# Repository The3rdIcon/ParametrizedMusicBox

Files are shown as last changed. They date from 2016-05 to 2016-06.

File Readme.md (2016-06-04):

# Program to generate a customizable music box
The midiToNote python file can be run as follows
```
python midiToNote.py <midi file name> <track in midi to encode>
```
```
python midiToNote.py hot_cross_buns.mid 1

Could not find name of track
***********_******
***********_******
*********_********
*********_********
*******_**********
*******_**********
***********_******
***********_******
*********_********
*********_********
*******_**********
*******_**********
*******_**********
*******_**********
*******_**********
*******_**********
*******_**********
*******_**********
*******_**********
*******_**********
*********_********
*********_********
*********_********
*********_********
*********_********
*********_********
*********_********
*********_********
***********_******
***********_******
*********_********
*********_********
*******_**********
*******_**********

oooooooooooXoooooooooooooooooXoooooooooooooooXoooooooooooooooooXoooooooooooooooXoooooooooooooooooXoooooooooooooooooooooXoooooooooooooooooXoooooooooooooooXoooooooooooooooooXoooooooooooooooXoooooooooooooooooXoooooooooooooooooXoooooooooooooooooXoooooooooooooooooXoooooooooooooooooXoooooooooooooooooXoooooooooooooooooXoooooooooooooooooXoooooooooooooooooXoooooooooooooooooooXoooooooooooooooooXoooooooooooooooooXoooooooooooooooooXoooooooooooooooooXoooooooooooooooooXoooooooooooooooooXoooooooooooooooooXoooooooooooooooooooXoooooooooooooooooXoooooooooooooooXoooooooooooooooooXoooooooooooooooXoooooooooooooooooXoooooooooo

C 4C#4D 4D#4E 4F 4F#4G 4G#4A 4A#4B 4C 5C#5D 5D#5E 5F 5

Timeslots: 34

```

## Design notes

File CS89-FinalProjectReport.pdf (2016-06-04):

# The Music Box Project

## Lau, Moreno, Solanky

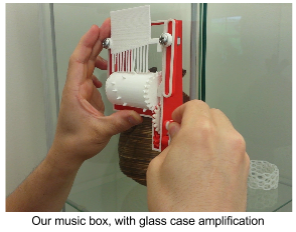
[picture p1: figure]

## 1. Motivation

Historically, humans have produced musical instruments from as wide a variety of materials and technologies as they have had access to. The profound power of computational fabrication lies in a greater facility for reproducing a work of imagination precisely in physical form. The ideal version of our project would enable a user to simply hum or whistle a tune into their microphone or take a picture of some sheet music, and automatically produce the design for a music box that would faithfully reproduce the user’s input.

## 2. Related Work

The resonant qualities of plastic are generally not suitable for musical instruments, which is why they are commonly made from metal or wood. However, working musical instruments have been made with 3D printers. Engineer Hans Fouche⁴ and industrial designer Scott Summit

6 have both
independently printed working guitars. The sound of string instruments and music boxes both work via the principle of forced vibration, indicating that the acoustics of 3D printed music boxes can sound good, even in plastic.

Very little work has been done in the specific area of 3D printable music boxes. Philipp Tiefenbacher, aka wizard23, published a scad file for a working music box on Thingiverse⁷
, a website for users to share open source design files. Tiefenbacher’s music box has several drawbacks. The comb and the case are produced as a single piece, which is inefficient for iteration and customization and damps the vibration of the comb unnecessarily. The herringbone gears have small crevices in which stuck support material and small errors in fabrication can produce noise and cause the gears to come out of alignment.

MIT students Tiffany Lu and Trevor Walker have also published code on GitHub
for producing an entirely 3D printed music box.

3 Their design initially called for a

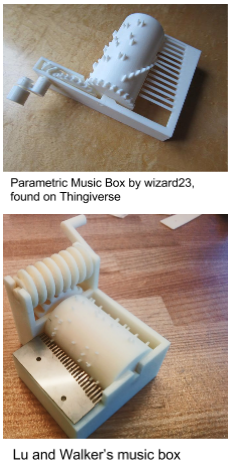
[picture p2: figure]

laser cut steel comb, however the steel was not flexible enough and broke the plastic pins off the cylinder.

The plastic comb they used instead did not have good acoustic qualities. For the playing mechanism, they used a large worm gear that was both materially inefficient and difficult to use.

We decided to use Tiefenbacher’s design as a starting point for several reasons. The design is compact, the code is relatively well structured for augmentation, and most importantly the comb produces a workable sound.

## 3. Technical Approach

## A. Modularity

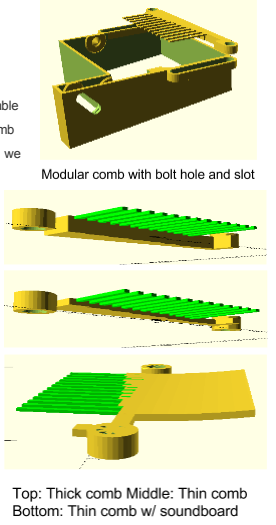
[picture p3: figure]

In order to tighten the iteration cycles in designing the musical comb and enable greater flexibility in customizing the arrangement of notes, we divided the comb and the case into separate modules. In order to fasten the modules together, we added bolt holes to the comb and corresponding slots on the case. Using
this system, combs with different notes sequences can be fabricated and substituted for use with a single case.

## B. Audio

### I. Material Resonance

Taking inspiration from the soundboards of string instruments, we modified the now modular comb further by thinning and extending the body of the comb. Soundboards are thin so that they are more easily affected by forced vibration, and they have large surface area in order to vibrate a greater amount of air, thus amplifying the sound of the instrument’s strings.

The main benefit for our music box is not in amplification of the sound, but
in having a greater proportion of the music box’s material vibrating at the
right frequency. The soundboard is largely free of the damping forces of
the rest of the music box. With the soundboard, a lesser amount of the energy propagated through the system via forced vibration is transferred into the resonant frequencies of the case, and instead is transferred to the soundboard, which vibrates more freely. This appears to have the effect of both clearer and longer sustained notes.

### II. Pitch Accuracy

When plucked, the teeth of the comb oscillate at a frequency f determined by the length L and height h of the tooth, the stiffness E and density ρ of the printing material, and γ , the constant for the first mode of a cantilever beam.

2 Equation (1) describes this relationship as it is used in our code, as the length of each tooth is to be determined by the target frequency.

### (1) L = √⁴π∙f

γ ∙h²
∙

√ E
3ρ

Unfortunately, the material constants E and ρ are unknown to us. Due to the variabilities inherent to the printing process, the stiffness and density may even differ between teeth on a single comb. Certainly there are minor variations in the dimensions of the teeth as well, due to difficulties in the removal of support structures.

In order to approximate the ratio , we first measured the frequency responses of the teeth of a test comb. E
3ρ
With those frequencies and the dimensions of a set of thirteen teeth, we have thirteen sets of values for equation (2), which is a simple reformulation of (1). By averaging the resulting values for , we can E
3ρ
approximate the correct material constants.
(2) E

3ρ = ( γ ∙h²
L ∙4π∙f ²

)

2

## C. Song to Cylinder Mapping

To allow for user specified songs to be be played with the music box, we experimented with a few approaches but ended up using two methods. Specifically we implemented methods to create an STL of the music cylinder with the required pin map from a MIDI, WAV format or recorded audio. The process involved dividing input sounds into chunks and extracting the dominant note using a frequency analysis of the input sound. This created the required note per time chunk format that was then passed to an SCAD file to create an STL music cylinder with the required pin mapping. We tested our system with synthetic tunes created in WAV format songs, specifically a 44KHz, 16-bit WAV file. These tunes were created using SonicPi

5
, an
algorithmic music application. We first attempted implementing the FFT analysis of the sound by passing microphone and sound recording through a custom GnuRadio² pipeline. This provided us realtime waterfall images of the frequency response of the input sound. Extending this pipeline to get notes per time chunk proved difficult due to its visual programming paradigm. Thus we shifted to a purely python based implementation for our program. While we tried other input mechanisms that could be implemented in future work like sheet music, ABC notation⁸ to tunes. The method used required the least effort given the timeconstraints. The programming methodology involved lots of empirical analysis of what kind of frequency responses were being produced by different notes, sampling rates and tune length. After much experimentation involving data collection and analysis of variation in extracted note versus input note frequencies for different input formats. We derived a pitch multiplier magic number (3) for a 44KHz, 16-bit and 5 second tune in WAV format divided into 35 time slots.

### (3) Pitch Multiplier = 12.2

With this multiplier we were able to extract the correct notes for all input sounds with the above constraints.

The pitch data was normalized according to (4) to make it independent of the sampling rate, duration of the WAV file and the time slots available on the cylinder, which decided the number of chunks a tune was to be chopped into.

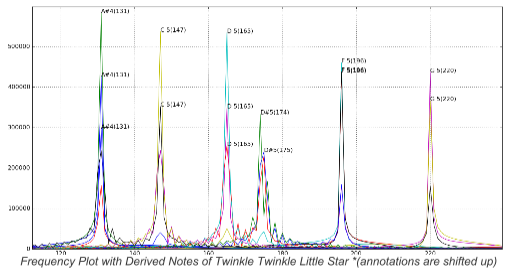
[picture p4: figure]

(4) Pitch Normalizer = ( | ) 229376

data length × 44000

sampling rate × 36

time slots −1

## D. Notes to Cylinder Mapping

The SCAD file can take take a mapping of pins on the music cylinder in a serialized X(pin) and o(nopin) format. This pin mapping format is created by our tune to cylinder mapping program and passed as arguments for the SCAD file to create an STL file. The whole pipeline is automated from the input tune provided by the user to the output STL file created by the program. The pin mapping is visualized in the figure on the right.

We also created an optimization to increase time slots available on a given cylinder for tunes using
less than half an octave of notes. If a tune used fewer than six notes, we double the positions

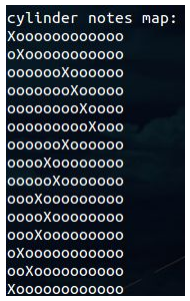
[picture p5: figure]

available on cylinder for each note and duplicate each note teeth. This allowed us to add more time slots to the cylinder as consecutive notes were not put at the same teeth. Thus the distance between time slots, which was previously constrained by the rotation required to pluck a teeth, can be reduced. This effectively allowed us to increase the granularity or length of the tune playable on the music box while keeping the cylinder diameter constant for simple tunes.

## E. A second song to cylinder approach

As noted above, the SCAD file takes a string of X(pin) and o(nopin) format in order to determine where to place the notes on the cylinder. To generate this mapping we also implemented a system whereby a user can pass a midi file into the system and generate a pin mapping and the corresponding notes.

The midi file format essentially consists of tracks which are represented as arrays of events. Each midi event then contains the metadata for said event. For example a NoteOn event contains the tick (relative to the previous tick) that the note starts on as well as the integer representation of the note that should be played on that tick, while a setTempoEvent will contain the tempo of the song.

Using these events it is relatively simple to go from a midi file to the note mapping that we need. First we get the track that we are going to transcribe and change the ticks to be absolutely positioned in time instead of relative to the previous tick (this makes it easier to map on the cylinder). We then get the unique notes by looping through the track events and adding the pitch names to a set. From this, we sort the notes based on musical notation starting from C4. This is an arbitrary start note for our testing purposes but it does not matter so long as the notes are sorted from lowest to highest. Once we have this we simply loop through the events in the track and add the event to the final string based off of the time that the tick occurs and then output the string along with the ordered list of notes for use in our SCAD file.

Limitations

Currently the timing is off for certain songs due to the nature of midi files. Midi is a very forgiving format and so a lot of midi files from the web are missing crucial parts such as the song tempo or tick time.

## 4. Results

In order to evaluate the sound of the music box, we used applied the fourier transform to the sound of individual teeth, and plotted the results against the background of the array of target frequencies. At first, the largest discernible peaks in the frequencies were clumped together, with no real differentiation between separate teeth. These frequencies, consistent from tooth to tooth, are presumed to be the resonating frequencies of the comb. Accordingly, the plot changed significantly as we reshaped the comb to resemble a soundboard, whereby different teeth came to have more distinct frequencies, overcoming the inherent noise of the system.

With the estimates of E and ρ provided by Tiefenbacher, we found the resulting frequencies were about three octaves higher than predicted. Due to the material interference described above, it was difficult to determine which of the measured frequencies corresponded to the predicted frequency of (1), so it took several iterations of evaluating equation (2) for the teeth with distinct responses, averaging the results, and updating the model before converging on 35560 E
3ρ ≈ 8

Even with this improved estimate, the resulting teeth do not perfectly match their target frequencies. In order to compensate for these unavoidable errors, we can extend the tooth length by a small percentage, which will ensure the resulting frequency will be slightly lower than the target frequency, and then sand down the sides of the tooth until the frequency is raised to the target.

On the tune to cylinder mapping front, after evaluating multiple mechanisms we ended up using two input formats: WAV and MIDI to extract the dominant note sequence and cylinder pin mapping to faithfully reproduce the tune. For the WAV input format we had to make the system independent of the available timeslots on the cylinder, sampling frequency and length of the tune using the normalization factor (4).

We created a working prototype that put together the
comb and the cylinder programs to test our tune
reconstruction. Qualitative testing suggested that we

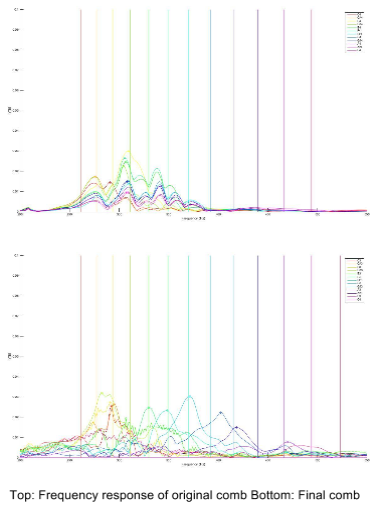
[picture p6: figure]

were able to recreate the desired tune but with ample room for improvement in audio quality.

## 5. Limitations

In order for the frequency of vibration to be perceptible, the teeth need to be quite thin. Unfortunately, the printing material is fragile at the required thinness, and the teeth can easily break while removing support structures or during use. The quality of the sound is still quite dull, as plastic is not very resonant. In addition to the fundamental inconsistencies in the teeth, the mechanics of the music box are affected by small errors, which can produce noise and malfunctions. The length of a song that can be faithfully reproduced is limited by the circumference of the cylinder and the required displacement of teeth for a good sounding pluck. Our input method was tested only with simple synthetic sounds from WAV files, not the common lossy and multitonal files that users are likely to have on hand.

## 6. Conclusions & Future Work

After much experimentation with the comb geometry and notes to cylinder mapping. We ended up creating a rudimentary but functional, tune to custom music box pipeline that we had proposed at the start of the project. The current mechanism can take in simple user input synthetic tunes and output a modular and fully 3D printable music box. Future work would involve improving the acoustic qualities of our system with a more holistic analysis of the comb and case resonance, e.g. with the finite element method. Further improvements like a graphical frontend and the ability to deal with more involved tunes may help ease usability and practicality of our software. More generally, computational fabrication opens up new avenues for designing simple objects, and our current music box design is still beholden to older fabrication processes. The comb inherently interferes with the acoustics, the length of songs are limited by the cylinder, so combless, cylinderless solutions should be explored. Combs and cylinders are after all just composites of extremely basic geometric shapes, and it is entirely likely that nonobvious topologies could sufficiently address these limitations. While using nonplastic material like metals could have improved the acoustics of our music box, we wanted to create a fully 3D printable music box to allow a wider set of users the ability to create their very own music boxes.

## References

1. Durchschlagende Zunge. (n.d.). Retrieved June 03, 2016, from https://de.wikipedia.org/wiki/Durchschlagende_Zunge#Berechnung_der_Tonh.C3.B6he
2. Home page GNU Radio. (n.d.). Retrieved June 03, 2016, from http://gnuradio.org/
3. Lu, T., & Walker, T. (n.d.). Music Box Generation from MIDIs. Retrieved from https://github.com/tweilu/6.s079-musicbox/blob/master/Documentation/6.S079FinalReport.pdf (https://github.com/tweilu/6.s079-musicbox/blob/master/Documentation/6.S079FinalReport.pdf)
4. Scott, C. (2015). The Remarkable Hans Fouche Returns with a 3D Printed Acoustic Guitar. Retrieved June 03, 2016, from https://3dprint.com/110959/hansfouche-3dprintedguitar/ (https://3dprint.com/110959/hans-fouche-3d-printed-guitar/)
5. Sonic Pi. (n.d.). Retrieved June 03, 2016, from http://sonicpi.net/ (http://sonic-pi.net/)
6. Summit, S. (n.d.). 3D PRINTED ACOUSTIC GUITAR. Retrieved June 03, 2016, from http://www.summitid.com/#/island/
7. Tiefenbacher, P. (n.d.). Parametric Music Box by wizard23. Retrieved June 03, 2016, from http://www.thingiverse.com/thing:53235
8. Abc notation blog. (n.d.). Retrieved June 03, 2016, from http://abcnotation.com/blog/2010/01/31/howtounderstandabcthebasics/

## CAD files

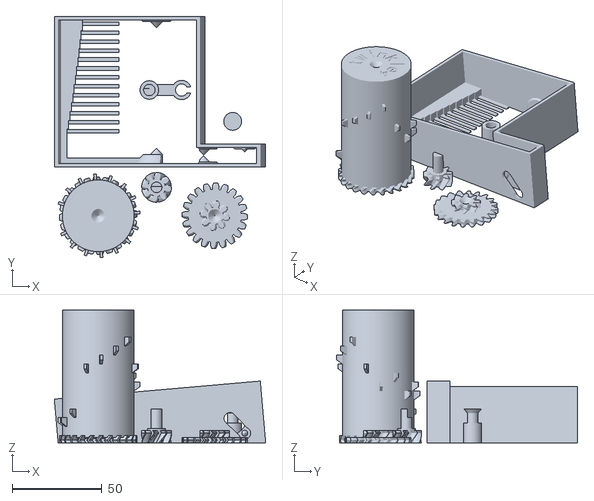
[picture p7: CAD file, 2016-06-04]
wav2musicbox/cylinder.stl
117.9 x 134.5 x 74.0

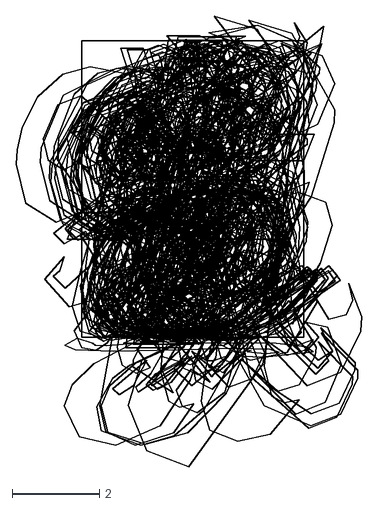
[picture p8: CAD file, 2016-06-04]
wav2musicbox/include/BlackRose.dxf
7.90 x 10.3

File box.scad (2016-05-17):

/*
 * Fully Printed Parametric Music Box With Exchangeable Song-Cylinders
 * Copyright (C) 2013  Philipp Tiefenbacher <wizards23@gmail.com>
 *
 * This program is free software; you can redistribute it and/or modify
 * it under the terms of the GNU General Public License as published by
 * the Free Software Foundation; either version 2 of the License, or
 * (at your option) any later version.
 *
 * This program is distributed in the hope that it will be useful,
 * but WITHOUT ANY WARRANTY; without even the implied warranty of
 * MERCHANTABILITY or FITNESS FOR A PARTICULAR PURPOSE.  See the
 * GNU General Public License for more details.
 *
 * The latest version can be found here:
 * https://github.com/wizard23/ParametrizedMusicBox
 *
 * contibutions welcome! please send me pull requests!
 *
 * This project was started for the Thingiverse Customizer challenge
 * and is online customizable here:
 * http://www.thingiverse.com/thing:53235/
 *
 *
 * Changelog:
 *
 * 2013-03-09, wizard23
 * added name of song using write.scad
 * fixed pulley position on print plate
 *
 */



use <MCAD/involute_gears.scad>
use <write/Write.scad>

// model config
// Is this to generate models for 3D printing or for the assembled view?
FOR_PRINT=1; // [0:Assembled, 1:PrintPlate]
// Should the MusicCylinder be generated?
GENERATE_MUSIC_CYLINDER=1; // [1:yes, 0:no]
// Should the Transmission Gear be generated?
GENERATE_MID_GEAR=1; // [1:yes, 0:no]
// Should the CrankGear be generated?
GENERATE_CRANK_GEAR=1; // [1:yes, 0:no]
// Should the Case (including the vibrating teeth) be generated?
GENERATE_CASE=1; // [1:yes, 0:no]
// Should the Crank be generated?
GENERATE_CRANK=1; // [1:yes, 0:no]
// Should the Pulley for the Crank be generated?
GENERATE_PULLEY=1; // [1:yes, 0:no]


// cylinder config
// this text will be put on top of the music cylinder
MusicCylinderName="test song";
// What font do you want to use for the text?
MusicCylinderNameFont="write/Letters.dxf"; //["write/Letters.dxf":Basic,"write/orbitron.dxf":Futuristic,"write/BlackRose.dxf":Fancy]
// how large should the font be
MusicCylinderNameFontSize = 8;
// how deep should the name be carved in?
MusicCylinderNameDepth=0.6;
// should the text be on the top or on the bottom of the music cylinder?
MusicCylinderNamePosition=0; // [0:top, 1:bottom]

// the width of all the walls in the design.
wall_width=2;


// Teeth config
// how many vibrating teeth should there be? (also number of available notes)
// You can use the output of the generator for this field:
// http://www.wizards23.net/projects/musicbox/musicbox.html
notes_count = 13;

// what should the notes on the teeth be? Each note is encoded by 3 characters:
// note (C,D,E,F,G,A,B), then the accidental (#, b or blank), and then the a
// one digit octave. You can use the output of the generator for this field:
// http://www.wizards23.net/projects/musicbox/musicbox.html
teethNotes="C 0C#0D 0D#0E 0F 0F#0G 0G#0A 0A#0B 0C 1C#1D 1D#1E 1F 1";

// how many time slots should there be? (If you make this much higher you
// should also increase musicCylinderGearTeeth) You can use the output of the
// generator for this field:
// http://www.wizards23.net/projects/musicbox/musicbox.html
time_slot_count = 35;

// the actual song. each time slot has notes_count characters.
// X marks a pin everything else means no pin.
// You can use the output of the generator for this field:
// http://www.wizards23.net/projects/musicbox/musicbox.html
pins="XoooooooooooooXoooooooooooooXoooooooooooooXoooooooooooooXoooooooooooooXoooooooooooooXoooooooooooooXoooooooooooooXoooooooooooooXoooooooooooooXoooooooooooooXoooooooooooooXoooooooooooooXoooXooXoooooooooooooooooooXoooXooXoooooooooooooooooooXoooXooXoooooooooooooooooooXoooXooXoooooooooooooooooooXoooXooXoooooooooooooooooooXoooXooXoooooooooooooXooXoooXoooooooooooooooooooXooXoooXoooooooooooooooooooXooXoooXoooooooooooooooooooXooXoooXoooooooooooooooooooXooXoooXoooooooooooooooooooXooXoooX";


// Gear Config
// the number of teeth on the music cylinder gear
musicCylinderGearTeeth = 24;
// nr of teeth on small transmission gear
midSmallTeeth = 8;
// nr of teeth on big transmission gear (for highest gear ratio this should be comparable but slightly smaller than musicCylinderGearTeeth)
midBigTeeth = 20;
// nr of teeth on crank gear
crankTeeth = 8;
// the angle of the teeth relative to the cylinder
// (0 would be normal to cylinder, should be some small (<10) positive angle)
cylinderGearTeethAngle = 5;
// the transmission gears angle
// (to help get the music cylinder out easily this should be negative)
midGearAngle = -5;
// should be positive but the gear must still be held by the case...
// TODO: calculate this automagically from heigth and angle...
crankGearAngle = 15;
// diametral pitch of the gear (if you make it smaller the teeth become bigger
//  (the addendum becomes bigger) I think of it as teeth per unit :)
diametral_pitch = 0.6;
// the height of all the gears
gearHeight = 3;
// higher tolerance makes the teeth thinner and they slip, too low tolerance jams the gears
gear_tolerance = 0.1;
// used for the distance between paralell gears that should not touch
// (should be slightly larger than your layer with)
gear_gap = 1;
gear_min_gap = 0.1;
gear_hold_R = 4;


// direction that crank hast to be turned it to play the song
// (has a bug: music is played backwards in clockwise mode so better leave it
// counter clockwise)
// [1:Clockwise, 0:CounterClockwise]
crankDirection = 0;

// HoldderH is the height of the axis kegel
// how far should the snapping axis that holds the crank gear be?
// (should smaller than the other two because its closer to the corner
// of the case)
crankAxisHolderH = 1.55;

// how far should the snapping axis that holds the transmission gear be?
midAxisHolderH = 3.3;

// how far should the snapping axis that holds the music cylinder be?
musicAxisHolderH = 3.4;




// for extra distance from axis to gears
snapAxisSlack = 0.35;
// for crank gear axis to case
axisSlack = 0.3;

// used for clean CSG operations
epsilonCSG = 0.1;

// reduce this for faster previews
$fn=32;

// Replace Gears with Cylinders to verify gear alignment
DEBUG_GEARS=0; // [1:yes, 0:no]

// Crank
crankSlack = 0.2;
crankAxisR = 3;
crankAxisCutAway = crankAxisR*0.8;
crankLength = 18;
crankAxisCutAwayH = 4;
crankExtraH=4;
crankH=crankExtraH+2*crankAxisCutAwayH;

// pulley
pulleySlack = 0.4;
pulleyH = 10;
pulleyR = crankAxisR+wall_width;
// cutout to get Pulley in
pulleySnapL=1.2;

// Constants
// the density of PLA (or whatever plastic you are using) in kg/m3
// ((( scientiffically derived by me by taking the average of the density values
// I could find onthe net scaled a little bit to take into account that the
// print is not super dense (0.7 * (1210 + 1430)/2) )))
ro_PLA = 924;
// elasticity module of the plastic you are using in N/m2 ((( derived by this
// formula I hope I got the unit conversion right 1.6*   1000000 *(2.5+7.8)/2 )))
E_PLA = 8240000;
// the gamma factor for the geometry of the teeth (extruded rectangle),
// use this to tune it if you have a finite state modell of the printed teeth :)
// taken from
// http://de.wikipedia.org/wiki/Durchschlagende_Zunge#Berechnung_der_Tonh.C3.B6he
gammaTooth = 1.875;
// the frequency of C0 (can be used for tuning if you dont have a clue about
// the material properties of you printing material :)
baseFrequC0 = 16.3516;

// This controls the size of the pins on the cylinder
pinHeight = 3;
pteethMinD = 1.5;
pinD=1.5;

// Comb Config
teethHeight = 3 * 0.3;
teethGap = pinHeight;
teethHolderW=5;
teethHolderH=5;

boltHoleInnerRadius = 5 * 0.65;
boltHoleOuterRadius = 5;


circular_pitch = 180/diametral_pitch;
addendum = 1/diametral_pitch;
// The height of the song cylinder
musicH=notes_count*(wall_width+teethGap);

// Derived Music stuff
pinStepX = musicH/notes_count;
pinStepY = 360/time_slot_count;

teethW = pinStepX-teethGap;
maxTeethL = TeethLen(0); // convention index 0 is lowest note

///////////////////////

musicCylinderRadius = (musicCylinderGearTeeth/diametral_pitch)/2;
midSmallR = (midSmallTeeth/diametral_pitch)/2;
midBigR = (midBigTeeth/diametral_pitch)/2;
crankR = (crankTeeth/diametral_pitch)/2;
centerForCrankGearInsertion=(midBigR+crankR)/2;
noteExtend = teethHolderW + maxTeethL + pteethMinD;
midGearDist = musicCylinderRadius+midSmallR;
crankDist = midBigR+crankR;
midGearXPos = cos(midGearAngle)*midGearDist;
midGearZPos = sin(midGearAngle)*midGearDist;
crankGearXPos = midGearXPos + cos(crankGearAngle)*crankDist;
crankGearZPos = midGearZPos + sin(crankGearAngle)*crankDist;
maxMusicAddendum = 1.5*max(addendum, pinHeight);
frameH = max(musicCylinderRadius, -midGearZPos+midBigR) + maxMusicAddendum;
gearBoxW = 2 * (gearHeight+gear_gap+wall_width) + gear_gap;
songH = musicH+teethGap+teethGap;
frameW = gearBoxW + songH;
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

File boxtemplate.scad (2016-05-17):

/*
 * Fully Printed Parametric Music Box With Exchangeable Song-Cylinders
 * Copyright (C) 2013  Philipp Tiefenbacher <wizards23@gmail.com>
 *
 * This program is free software; you can redistribute it and/or modify
 * it under the terms of the GNU General Public License as published by
 * the Free Software Foundation; either version 2 of the License, or
 * (at your option) any later version.
 *
 * This program is distributed in the hope that it will be useful,
 * but WITHOUT ANY WARRANTY; without even the implied warranty of
 * MERCHANTABILITY or FITNESS FOR A PARTICULAR PURPOSE.  See the
 * GNU General Public License for more details.
 *
 * The latest version can be found here:
 * https://github.com/wizard23/ParametrizedMusicBox
 *
 * contibutions welcome! please send me pull requests!
 *
 * This project was started for the Thingiverse Customizer challenge
 * and is online customizable here:
 * http://www.thingiverse.com/thing:53235/
 *
 *
 * Changelog:
 *
 * 2013-03-09, wizard23
 * added name of song using write.scad
 * fixed pulley position on print plate
 *
 */



use <MCAD/involute_gears.scad>
use <write/Write.scad>

// model config
// Is this to generate models for 3D printing or for the assembled view?
FOR_PRINT={{.ShouldPrint}}; // [0:Assembled, 1:PrintPlate]
// Should the MusicCylinder be generated?
GENERATE_MUSIC_CYLINDER={{.ShouldGenerateCylinder}}; // [1:yes, 0:no]
// Should the Transmission Gear be generated?
GENERATE_MID_GEAR={{.ShouldGenerateTransmissionGear}}; // [1:yes, 0:no]
// Should the CrankGear be generated?
GENERATE_CRANK_GEAR={{.ShouldGenerateCrankGear}}; // [1:yes, 0:no]
// Should the Case (including the vibrating teeth) be generated?
GENERATE_CASE={{.ShouldGenerateCase}}; // [1:yes, 0:no]
// Should the Crank be generated?
GENERATE_CRANK={{.ShouldGenerateCrank}}; // [1:yes, 0:no]
// Should the Pulley for the Crank be generated?
GENERATE_PULLEY={{.ShouldGeneratePulley}}; // [1:yes, 0:no]


// cylinder config
// this text will be put on top of the music cylinder
MusicCylinderName={{.SongName}};
// What font do you want to use for the text?
MusicCylinderNameFont="write/Letters.dxf"; //["write/Letters.dxf":Basic,"write/orbitron.dxf":Futuristic,"write/BlackRose.dxf":Fancy]
// how large should the font be
MusicCylinderNameFontSize = 8;
// how deep should the name be carved in?
MusicCylinderNameDepth=0.6;
// should the text be on the top or on the bottom of the music cylinder?
MusicCylinderNamePosition=0; // [0:top, 1:bottom]

// the width of all the walls in the design.
wall_width=2;

// Teeth config
// how many vibrating teeth should there be? (also number of available notes)
// You can use the output of the generator for this field:
// http://www.wizards23.net/projects/musicbox/musicbox.html
notes_count = 13;

// what should the notes on the teeth be? Each note is encoded by 3 characters:
// note (C,D,E,F,G,A,B), then the accidental (#, b or blank), and then the a
// one digit octave. You can use the output of the generator for this field:
// http://www.wizards23.net/projects/musicbox/musicbox.html
teethNotes="C 0C#0D 0D#0E 0F 0F#0G 0G#0A 0A#0B 0C 1C#1D 1D#1E 1F 1";

// how many time slots should there be? (If you make this much higher you
// should also increase musicCylinderGearTeeth) You can use the output of the
// generator for this field:
// http://www.wizards23.net/projects/musicbox/musicbox.html
time_slot_count = 35;

// the actual song. each time slot has notes_count characters.
// X marks a pin everything else means no pin.
// You can use the output of the generator for this field:
// http://www.wizards23.net/projects/musicbox/musicbox.html
pins="XoooooooooooooXoooooooooooooXoooooooooooooXoooooooooooooXoooooooooooooXoooooooooooooXoooooooooooooXoooooooooooooXoooooooooooooXoooooooooooooXoooooooooooooXoooooooooooooXoooooooooooooXoooXooXoooooooooooooooooooXoooXooXoooooooooooooooooooXoooXooXoooooooooooooooooooXoooXooXoooooooooooooooooooXoooXooXoooooooooooooooooooXoooXooXoooooooooooooXooXoooXoooooooooooooooooooXooXoooXoooooooooooooooooooXooXoooXoooooooooooooooooooXooXoooXoooooooooooooooooooXooXoooXoooooooooooooooooooXooXoooX";


// Gear Config
// the number of teeth on the music cylinder gear
musicCylinderGearTeeth = 24;
// nr of teeth on small transmission gear
midSmallTeeth = 8;
// nr of teeth on big transmission gear (for highest gear ratio this should be comparable but slightly smaller than musicCylinderGearTeeth)
midBigTeeth = 20;
// nr of teeth on crank gear
crankTeeth = 8;
// the angle of the teeth relative to the cylinder
// (0 would be normal to cylinder, should be some small (<10) positive angle)
cylinderGearTeethAngle = 5;
// the transmission gears angle
// (to help get the music cylinder out easily this should be negative)
midGearAngle = -5;
// should be positive but the gear must still be held by the case...
// TODO: calculate this automagically from heigth and angle...
crankGearAngle = 15;
// diametral pitch of the gear (if you make it smaller the teeth become bigger
//  (the addendum becomes bigger) I think of it as teeth per unit :)
diametral_pitch = 0.6;
// the height of all the gears
gearHeight = 3;
// higher tolerance makes the teeth thinner and they slip, too low tolerance jams the gears
gear_tolerance = 0.1;
// used for the distance between paralell gears that should not touch
// (should be slightly larger than your layer with)
gear_gap = 1;
gear_min_gap = 0.1;
gear_hold_R = 4;


// direction that crank hast to be turned it to play the song
// (has a bug: music is played backwards in clockwise mode so better leave it
// counter clockwise)
// [1:Clockwise, 0:CounterClockwise]
crankDirection = 0;

// HoldderH is the height of the axis kegel
// how far should the snapping axis that holds the crank gear be?
// (should smaller than the other two because its closer to the corner
// of the case)
crankAxisHolderH = 1.55;

// how far should the snapping axis that holds the transmission gear be?
midAxisHolderH = 3.3;

// how far should the snapping axis that holds the music cylinder be?
musicAxisHolderH = 3.4;

// pulley
pulleySlack = 0.4;
pulleyH = 10;
pulleyR = crankAxisR+wall_width;
// cutout to get Pulley in
pulleySnapL=1.2;


// for extra distance from axis to gears
snapAxisSlack = 0.35;
// for crank gear axis to case
axisSlack = 0.3;

// used for clean CSG operations
epsilonCSG = 0.1;

// reduce this for faster previews
$fn=32;

// Replace Gears with Cylinders to verify gear alignment
DEBUG_GEARS=0; // [1:yes, 0:no]

// Crank
crankSlack = 0.2;
crankAxisR = 3;
crankAxisCutAway = crankAxisR*0.8;
crankLength = 18;
crankAxisCutAwayH = 4;
crankExtraH=4;
crankH=crankExtraH+2*crankAxisCutAwayH;

// Constants
// the density of PLA (or whatever plastic you are using) in kg/m3
// ((( scientiffically derived by me by taking the average of the density values
// I could find onthe net scaled a little bit to take into account that the
// print is not super dense (0.7 * (1210 + 1430)/2) )))
ro_PLA = 924;
// elasticity module of the plastic you are using in N/m2 ((( derived by this
// formula I hope I got the unit conversion right 1.6*   1000000 *(2.5+7.8)/2 )))
E_PLA = 8240000;
// the gamma factor for the geometry of the teeth (extruded rectangle),
// use this to tune it if you have a finite state modell of the printed teeth :)
// taken from
// http://de.wikipedia.org/wiki/Durchschlagende_Zunge#Berechnung_der_Tonh.C3.B6he
gammaTooth = 1.875;
// the frequency of C0 (can be used for tuning if you dont have a clue about
// the material properties of you printing material :)
baseFrequC0 = 16.3516;

// This controls the size of the pins on the cylinder
pinHeight = 3;
pteethMinD = 1.5;
pinD=1.5;

// Comb Config
teethHeight = 3 * 0.3;
teethGap = pinHeight;
teethHolderW=5;
teethHolderH=5;

boltHoleInnerRadius = 5 * 0.65;
boltHoleOuterRadius = 5;


circular_pitch = 180/diametral_pitch;
addendum = 1/diametral_pitch;
// The height of the song cylinder
musicH=notes_count*(wall_width+teethGap);

// Derived Music stuff
pinStepX = musicH/notes_count;
pinStepY = 360/time_slot_count;

teethW = pinStepX-teethGap;
maxTeethL = TeethLen(0); // convention index 0 is lowest note

///////////////////////

musicCylinderRadius = (musicCylinderGearTeeth/diametral_pitch)/2;
midSmallR = (midSmallTeeth/diametral_pitch)/2;
midBigR = (midBigTeeth/diametral_pitch)/2;
crankR = (crankTeeth/diametral_pitch)/2;
centerForCrankGearInsertion=(midBigR+crankR)/2;
noteExtend = teethHolderW + maxTeethL + pteethMinD;
midGearDist = musicCylinderRadius+midSmallR;
crankDist = midBigR+crankR;
midGearXPos = cos(midGearAngle)*midGearDist;
midGearZPos = sin(midGearAngle)*midGearDist;
crankGearXPos = midGearXPos + cos(crankGearAngle)*crankDist;
crankGearZPos = midGearZPos + sin(crankGearAngle)*crankDist;
maxMusicAddendum = 1.5*max(addendum, pinHeight);
frameH = max(musicCylinderRadius, -midGearZPos+midBigR) + maxMusicAddendum;
gearBoxW = 2 * (gearHeight+gear_gap+wall_width) + gear_gap;
songH = musicH+teethGap+teethGap;
frameW = gearBoxW + songH;
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

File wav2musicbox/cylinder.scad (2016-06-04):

/*
 * Fully Printed Parametric Music Box With Exchangeable Song-Cylinders
 * Copyright (C) 2013  Philipp Tiefenbacher <wizards23@gmail.com>
 *
 * This program is free software; you can redistribute it and/or modify
 * it under the terms of the GNU General Public License as published by
 * the Free Software Foundation; either version 2 of the License, or
 * (at your option) any later version.
 *
 * This program is distributed in the hope that it will be useful,
 * but WITHOUT ANY WARRANTY; without even the implied warranty of
 * MERCHANTABILITY or FITNESS FOR A PARTICULAR PURPOSE.  See the
 * GNU General Public License for more details.
 *
 * The latest version can be found here:
 * https://github.com/wizard23/ParametrizedMusicBox 
 *
 * contibutions welcome! please send me pull requests!
 *
 * This project was started for the Thingiverse Customizer challenge
 * and is online customizable here:
 * http://www.thingiverse.com/thing:53235/ 
 *
 *
 * Changelog:
 *
 * 2013-03-09, wizard23
 * added name of song using write.scad
 * fixed pulley position on print plate
 *
 */

use <include/involute_gears.scad>
use <include/write.scad>

// Is this to generate models for 3D printing or for the assembled view?
FOR_PRINT=1; // [0:Assembled, 1:PrintPlate]

// Should the MusicCylinder be generated? 
GENERATE_MUSIC_CYLINDER=1; // [1:yes, 0:no]
// Should the Transmission Gear be generated?
GENERATE_MID_GEAR=1; // [1:yes, 0:no]
// Should the CrankGear be generated?
GENERATE_CRANK_GEAR=1; // [1:yes, 0:no]
// Should the Case (including the vibrating teeth) be generated?
GENERATE_CASE=1; // [1:yes, 0:no]
// Should the Crank be generated?
GENERATE_CRANK=1; // [1:yes, 0:no]
// Should the Pulley for the Crank be generated?
GENERATE_PULLEY=1; // [1:yes, 0:no]

// this text will be put on top of the music cylinder
MusicCylinderName="song";
// What font do you want to use for the text?
MusicCylinderNameFont="include/Letters.dxf"; //["include/Letters.dxf":Basic,"include/orbitron.dxf":Futuristic,"include/BlackRose.dxf":Fancy]
// how large should the font be
MusicCylinderNameFontSize = 8;
// how deep should the name be carved in?
MusicCylinderNameDepth=0.6;
// should the text be on the top or on the bottom of the music cylinder?
MusicCylinderNamePosition=0; // [0:top, 1:bottom]

// the width of all the walls in the design.
wall=2;

// how many vibrating teeth should there be? (also number of available notes) You can use the output of the generator for this field: http://www.wizards23.net/projects/musicbox/musicbox.html
pinNrX = 13;

// what should the notes on the teeth be? Each note is encoded by 3 characters: note (C,D,E,F,G,A,B), then the accidental (#, b or blank), and then the a one digit octave. You can use the output of the generator for this field: http://www.wizards23.net/projects/musicbox/musicbox.html
teethNotes="C 0C#0D 0D#0E 0F 0F#0G 0G#0A 0A#0B 0C 1C#1D 1D#1E 1F 1";

// how many time slots should there be? (If you make this much higher you should also increase musicCylinderTeeth) You can use the output of the generator for this field: http://www.wizards23.net/projects/musicbox/musicbox.html
pinNrY = 16;

// the actual song. each time slot has pinNrX characters. X marks a pin everything else means no pin. You can use the output of the generator for this field: http://www.wizards23.net/projects/musicbox/musicbox.html
pins="XoooooooooooooXoooooooooooooooooXoooooooooooooXoooooooooooooXoooooooooooooXoooooooooXooooooooooXoooooooooooooXooooooooooXoooooooooooooXoooooooooooXooooooooooXoooooooooooooXooooooooooXoooooooooooo";

// the number of teeth on the music cylinder
musicCylinderTeeth = 24;

// nr of teeth on small transmission gear
midSmallTeeth = 8;
// nr of teeth on big transmission gear (for highest gear ratio this should be comparable but slightly smaller than musicCylinderTeeth)
midBigTeeth = 20;
// nr of teeth on crank gear
crankTeeth = 8;

//// Constants 

// the density of PLA (or whatever plastic you are using) in kg/m3 ((( scientiffically derived by me by taking the average of the density values I could find onthe net scaled a little bit to take into account that the print is not super dense (0.7 * (1210 + 1430)/2) )))
ro_PLA = 924; 
// elasticity module of the plastic you are using in N/m2 ((( derived by this formula I hope I got the unit conversion right 1.6*   1000000 *(2.5+7.8)/2 )))
E_PLA = 8240000; 
// the gamma factor for the geometry of the teeth (extruded rectangle), use this to tune it if you have a finite state modell of the printed teeth :) taken from http://de.wikipedia.org/wiki/Durchschlagende_Zunge#Berechnung_der_Tonh.C3.B6he
gammaTooth = 1.875; 
// the frequency of C0 (can be used for tuning if you dont have a clue about the material properties of you printing material :)
baseFrequC0 = 16.3516;


// the angle of the teeth relative to the cylinder (0 would be normal to cylinder, should be some small (<10) positive angle)
noteAlpha = 5;
// the transmission gears angle (to help get the music cylinder out easily this should be negative)
midGearAngle=-5;
// should be positive but the gear must still be held by the case...TODO: calculate this automagically from heigth and angle...
crankGearAngle=15;

// diametral pitch of the gear (if you make it smaller the teeth become bigger (the addendum becomes bigger) I tink of it as teeth per unit :)
diametral_pitch = 0.6;
// the height of all the gears
gearH=3;

// direction that crank hast to be turned it to play the song (has a bug: music is played backwards in clockwise mode so better leave it counter clockwise)
crankDirection = 0; // [1:Clockwise, 0:CounterClockwise]


// HoldderH is the height of the axis kegel

// how far should the snapping axis that holds the crank gear be? (should smaller than the other two because its closer to the corner of the case)
crankAxisHolderH = 1.55;
// how far should the snapping axis that holds the transmission gear be?
midAxisHolderH=3.3;
// how far should the snapping axis that holds the music cylinder be?
musicAxisHolderH=3.4;
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

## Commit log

2016-05-17 Commented most of the code
    [box.scad]
2016-05-17 Add Readme
    [box.scad]
2016-05-17 Start SCAD File generator for GUI
    [boxtemplate.scad]
2016-05-17 :art: Add comments and clean up code
    [box.scad]
2016-06-04 michael's sutff
    [box_latest_comb.scad]
2016-06-04 WAV to notes to scad to music box STL
    [BlackRose.dxf, Letters.dxf, cylinder.scad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]
